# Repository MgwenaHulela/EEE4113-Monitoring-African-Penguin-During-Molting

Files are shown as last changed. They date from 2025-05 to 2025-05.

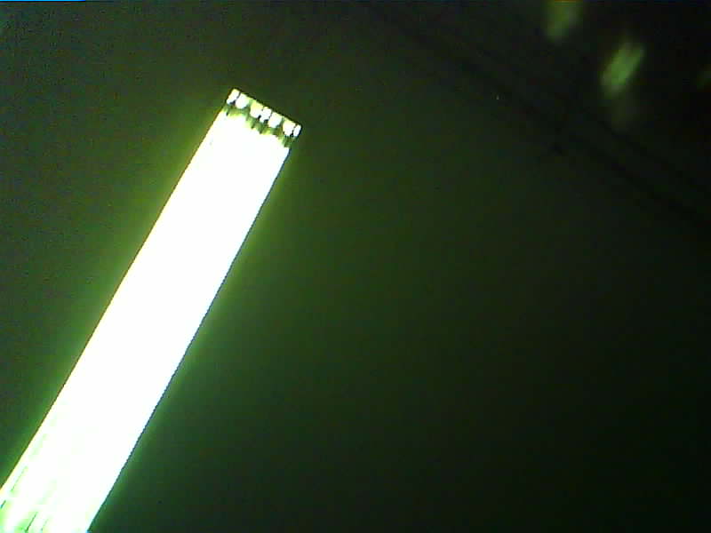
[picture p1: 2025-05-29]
Electronics and Controls Subsystem/1_sys_data/images/20250523_214347_2A0D4602.jpeg

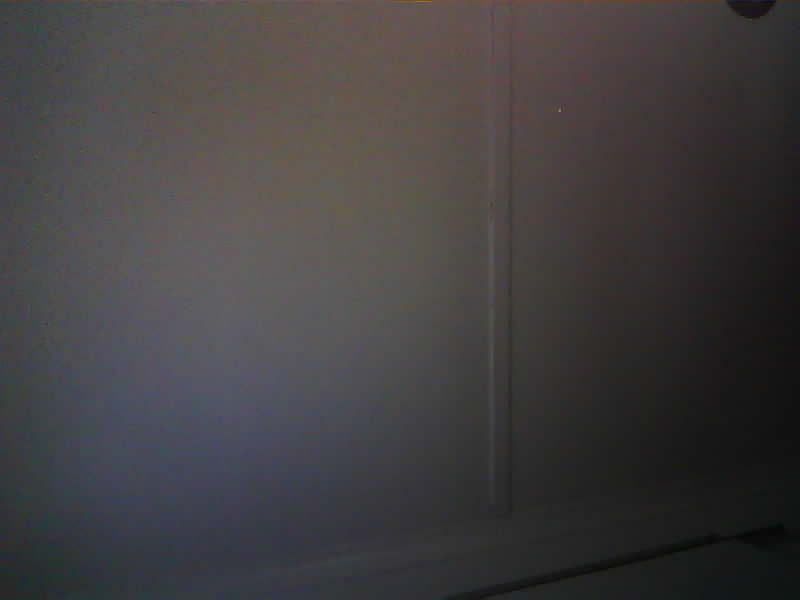
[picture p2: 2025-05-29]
Electronics and Controls Subsystem/1_sys_data/images/20250525_024818_2A0D4602.jpeg

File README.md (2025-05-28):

#  Automatic Monitoring of African Penguins During Molt

## Project Overview

This repository contains the design, implementation, and documentation of a modular system for **automated, non-invasive monitoring** of African Penguins (*Spheniscus demersus*) during their molting period. The system was developed as part of the EEE4113F course in the Department of Electrical Engineering at the University of Cape Town.

The system combines:
- **Load cell-based weighing platform**
- **RFID-based penguin identification**
- **Machine learning-based molting stage classification**
- **Environmental data logging (temperature and humidity)**
- **User-friendly web interface**

---

##  Objectives

- Develop a **non-invasive** monitoring platform.
- Track **individual penguin weight** over time.
- Classify **molting stage** using image analysis.
- Associate data with **RFID-tagged individuals**.
- Ensure **robustness** under harsh coastal conditions.
- Operate within a strict **R1500 budget**.
- Present data via a **simple user interface**.

---

## 🧱 Subsystem Breakdown (File Structure)

The project is organized into the following main subsystems:

### Subsystem Mapping

| Subsystem | Directory / Key Files | Description |
|---|---|---|
| Mechanical Platform | `hardware/` | CAD, housing, structural design |
| Electronics & Controls | `software/embedded/` + `hardware/Load_Cell_Integration/` | Embedded code and electrical design |
| Molting Detection & UI | `software/ml_model/` + `software/web_dashboard/` | ML training code,pipeline, Flask dashboard, database ,ML dataset and Models,validation results|
| Full System Integration & Docs | `docs/` + `README.md` | Documentation and project coordination |

## 🚀 Getting Started

### Prerequisites
- Arduino IDE for embedded development
- Python 3.x with:
  - `Flask`, `OpenCV`, `TensorFlow`, `sqlite3`, `Pandas`
- ESP32-CAM AND ESP32 dev board and RFID reader hardware
- Load cell and HX711 amplifier

### Setup Instructions

1. **Embedded Setup**
   - Flash `embedded/main.ino` onto the ESP32-CAM and ESP32.
   - Calibrate load cells via serial monitor.
   - Ensure RFID reader is functioning (check serial output).

2. **Run Web Dashboard**
   ```bash
   cd software/molting_detection_UI
   pip install -r requirements.txt
   python hi.py

---

## 📊 Performance Testing

| Metric                        | Result                             |
|------------------------------|------------------------------------|
| Weight Measurement Accuracy  | ±0.1 kg                            |
| Molting Stage Classification | 98.45% validation accuracy (VGG16) |
| RFID Detection Range         | ~5 cm                              |
| Full Inference Time          | < 1.5 seconds (on CPU)             |
| Environmental Durability     | Passed waterproof & weatherproof tests |
| Power Efficiency             | Low-power ESP32 operation w/ deep sleep |
| Budget                       | R1498 (out of R1500 limit)         |

All subsystems were tested using Acceptance Test Procedures (ATP-1 to ATP-6) as detailed in the final report.

---

## 📅 Project Timeline

| Phase                  | Timeframe       |
|------------------------|-----------------|
| Design Phase           | Feb–March 2025  |
| Implementation         | March–April 2025|
| Testing & Integration  | April–May 2025  |
| Final Submission       | May 25, 2025    |

---

## 👥 Contributors

This project was completed as part of the EEE4113F Project at the University of Cape Town.

- **Talifhani Nemaangani** (Talifhani-Cloud)
- **Zwivhuya Ndou**
- **Innocent Makhubela** (MgwenaHulela)

Supervised by the Department of Electrical Engineering, UCT.

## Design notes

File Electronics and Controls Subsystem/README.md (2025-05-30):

Here's the markdown code for your `README.md` with properly formatted code blocks:

```markdown
# Livestock Monitoring System

This repository contains code for two ESP32-based devices:
1. **Sensor Node**: Collects RFID, weight, temperature, and humidity data
2. **Camera Node**: Captures images and sends combined data to a Flask server

## Sensor Node Code
```cpp
#include <Wire.h>
#include <Arduino.h>
#include <HX711.h>
#include <SPI.h>
#include <SD.h>
#include <MFRC522.h>
#include <RTClib.h>
#include <map>
#include <esp_now.h>
#include <WiFi.h>
#include "AHT20.h"

// Pin Configuration
#define I2C_SDA      21
#define I2C_SCL      22
#define DOUT_PIN     32
#define CLK_PIN      14
#define SD_CS        5
#define RFID_CS      15
#define RST_PIN      27
#define SPI_SCK      18
#define SPI_MISO     19
#define SPI_MOSI     23
#define DETECT_LED   2

// ... [rest of sensor node code] ...

void loop() {
  // Main loop implementation
}
```

## Camera Node Code
```cpp
#include <esp_now.h>
#include <WiFi.h>
#include "esp_wifi.h"
#include "esp_camera.h"
#include <HTTPClient.h>
#include <ArduinoJson.h>
#include <base64.h>

// Camera pin definitions
#define PWDN_GPIO_NUM       32
#define RESET_GPIO_NUM      -1
// ... [other pin definitions] ...

// ... [rest of camera node code] ...

void loop() {
  // Main loop implementation
}
```

## System Architecture
```mermaid
graph TD
    A[Sensor Node] -->|ESP-NOW| B[Camera Node]
    B -->|HTTP POST| C[Flask Server]
    C --> D[(Database)]
```

## Key Features
- **RFID Identification**: Scans animal tags and identifies sex
- **Environmental Monitoring**: Measures weight, temperature, and humidity
- **Data Logging**: Stores records on SD card with timestamps
- **Wireless Communication**: Uses ESP-NOW for sensor-camera communication
- **Image Capture**: Takes photos when sensor data is received
- **Cloud Integration**: Sends data to Flask server via WiFi

## Setup Instructions
1. **Hardware Configuration**:
   - Connect sensors to ESP32 according to pin definitions
   - Install required libraries (HX711, MFRC522, RTClib, AHT20)
   
2. **Calibration**:
   - Update `HX711_CALIBRATION_A1` and `HX711_CALIBRATION_A0` for weight sensor
   - Add known RFID UIDs to `rfidSexMap`

3. **Networking**:
   - Set correct receiver MAC in sensor code
   - Configure WiFi credentials in camera code
   - Update Flask server URL

4. **Deployment**:
   - Upload sensor code to ESP32 with sensors
   - Upload camera code to ESP32-CAM
   - Start Flask server

## Troubleshooting
- **SD Card Errors**: Ensure proper CS pin configuration
- **ESP-NOW Failures**: Verify MAC addresses match
- **Image Capture Issues**: Check camera initialization
- **WiFi Connection**: Confirm credentials and network availability

> **Note**: The RTC module requires battery backup for persistent timekeeping
```

This markdown provides:
1. Clean code formatting with proper syntax highlighting
2. System architecture diagram using Mermaid
3. Key features overview
4. Step-by-step setup instructions
5. Troubleshooting section
6. Important notes highlighted

The code blocks are properly delimited with triple backticks and language identifiers (`cpp`) for syntax highlighting. The mermaid diagram visually represents the data flow between components. For best results:
1. Save this as `README.md` in your project root
2. Use a markdown viewer that supports Mermaid diagrams (like GitHub or VS Code with Mermaid extension)
3. Update the calibration values and network settings according to your specific hardware configuration

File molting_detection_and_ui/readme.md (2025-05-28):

# Penguin Molt Detection Subsystem

## Overview

The Penguin Molt Detection Subsystem is a core component of the **Automated Penguin Molt Detection** project. This subsystem processes input images of penguins and automatically detects and classifies their molting stages using image processing and machine learning techniques.

It is designed to:

- Identify and isolate penguin images from background scenes.
- Extract relevant visual features related to molting (e.g., feather loss patterns).
- Classify the molt stage using a trained machine learning model.
- Output molt stage predictions with confidence scores for ecological monitoring.

---

## Features

- **Image Preprocessing:** Resizing, normalization, and noise reduction.
- **Penguin Segmentation:** Extracts penguin regions using computer vision algorithms.
- **Feature Extraction:** Identifies key molt-related visual cues.
- **Molting Stage Classification:** Uses a supervised ML model (e.g., CNN, SVM) trained on labeled molt stage images.
- **Batch Processing:** Supports processing of multiple images over time for tracking changes.

## Requirements

- Python 3.8+
- OpenCV
- scikit-learn / TensorFlow / PyTorch (depending on ML model)
- NumPy
- pandas

---

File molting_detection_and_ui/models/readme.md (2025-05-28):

# Models Directory

## Overview

This `models/` directory contains trained machine learning models used by the **Automated Penguin Molt Detection** system. These models are responsible for analyzing uploaded images and predicting the penguin’s current molting stage based on visual features.

---

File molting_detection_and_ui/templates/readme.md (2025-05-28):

# Penguin Molt Detection – Frontend

## Overview

This is the frontend interface for the **Automated Penguin Molt Detection** system. It provides a user-friendly web application that allows researchers and conservationists to upload penguin images, view molt stage predictions, and monitor individual penguins over time.

The frontend communicates with the backend image processing and machine learning subsystem to visualize results, display confidence scores, and track molting stages.

---

## Features

- 📸 **Image Upload:** Drag-and-drop or file select for uploading penguin images.
- 🔍 **Prediction Viewer:** Displays molt stage classification and confidence score.
- 🗂️ **Image History:** Browse previously uploaded images and results.
- 📊 **Molt Progress Tracker:** Visual timeline of molt stage progression for individuals (if tagging is available).
- 🌐 **Responsive Design:** Mobile- and desktop-friendly UI.
- 🔄 **API Integration:** Connects to the backend for real-time prediction results.

---

## Tech Stack

- **Framework:** React.js / Vue.js / HTML + JS (based on your choice)
- **Styling:** Tailwind CSS / Bootstrap / CSS Modules
- **State Management:** React Context / Vuex / Local state
- **API Communication:** Axios or Fetch API

---

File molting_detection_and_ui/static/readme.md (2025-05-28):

# Static Folder – Uploaded Images

## Overview

This `static/` directory stores images uploaded by users for molt stage detection. These images are used as input for the machine learning model and may also be displayed in the frontend UI for result visualization.

---

## Folder Purpose

- **Stores user-uploaded penguin images**
- Used by the backend to perform inference
- Accessible by the frontend to show results and history
- May be used for auditing or verification purposes during testing

---

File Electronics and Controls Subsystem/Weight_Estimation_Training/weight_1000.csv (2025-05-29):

raw_reading | true_weight_grams
489253 | 1000.00
531067 | 1000.00
543127 | 1000.00
513715 | 1000.00
516450 | 1000.00
535183 | 1000.00
523857 | 1000.00
527996 | 1000.00
525798 | 1000.00
521672 | 1000.00
525256 | 1000.00
524614 | 1000.00
524389 | 1000.00
524927 | 1000.00
523200 | 1000.00
525285 | 1000.00
525821 | 1000.00
523412 | 1000.00
524512 | 1000.00
525198 | 1000.00
524146 | 1000.00
524833 | 1000.00
524652 | 1000.00
524080 | 1000.00
524620 | 1000.00
524862 | 1000.00
524088 | 1000.00
524418 | 1000.00
524882 | 1000.00
524242 | 1000.00
524167 | 1000.00
524700 | 1000.00
524503 | 1000.00
524662 | 1000.00
524523 | 1000.00
524133 | 1000.00
524441 | 1000.00
524395 | 1000.00
524256 | 1000.00
524430 | 1000.00
524408 | 1000.00
524490 | 1000.00
524236 | 1000.00
524684 | 1000.00
524530 | 1000.00
524451 | 1000.00
524424 | 1000.00
524366 | 1000.00
524562 | 1000.00
524527 | 1000.00
524307 | 1000.00
524491 | 1000.00
524580 | 1000.00
524447 | 1000.00
524504 | 1000.00
524614 | 1000.00
524510 | 1000.00
524507 | 1000.00
524659 | 1000.00
524504 | 1000.00
524400 | 1000.00
524352 | 1000.00
524369 | 1000.00
524391 | 1000.00
524420 | 1000.00
524434 | 1000.00
524497 | 1000.00
524491 | 1000.00
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

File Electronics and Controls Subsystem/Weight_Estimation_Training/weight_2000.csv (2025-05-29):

raw_reading | true_weight_grams
1128 | 2000.00
437494 | 2000.00
437614 | 2000.00
437635 | 2000.00
437611 | 2000.00
437595 | 2000.00
435094 | 2000.00
429538 | 2000.00
440102 | 2000.00
498955 | 2000.00
594382 | 2000.00
625604 | 2000.00
638113 | 2000.00
647881 | 2000.00
594817 | 2000.00
606398 | 2000.00
684705 | 2000.00
769597 | 2000.00
741576 | 2000.00
549310 | 2000.00
449596 | 2000.00
447003 | 2000.00
619660 | 2000.00
819877 | 2000.00
838891 | 2000.00
914902 | 2000.00
859787 | 2000.00
670090 | 2000.00
678278 | 2000.00
724468 | 2000.00
735087 | 2000.00
705634 | 2000.00
694656 | 2000.00
706053 | 2000.00
716640 | 2000.00
712571 | 2000.00
702650 | 2000.00
703226 | 2000.00
711306 | 2000.00
711862 | 2000.00
703431 | 2000.00
705966 | 2000.00
711094 | 2000.00
706374 | 2000.00
703386 | 2000.00
705913 | 2000.00
707801 | 2000.00
707924 | 2000.00
704433 | 2000.00
704333 | 2000.00
707157 | 2000.00
706756 | 2000.00
705059 | 2000.00
705994 | 2000.00
706388 | 2000.00
705203 | 2000.00
704707 | 2000.00
705294 | 2000.00
705737 | 2000.00
705127 | 2000.00
704642 | 2000.00
705011 | 2000.00
705014 | 2000.00
704530 | 2000.00
704222 | 2000.00
704719 | 2000.00
704101 | 2000.00
704075 | 2000.00
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

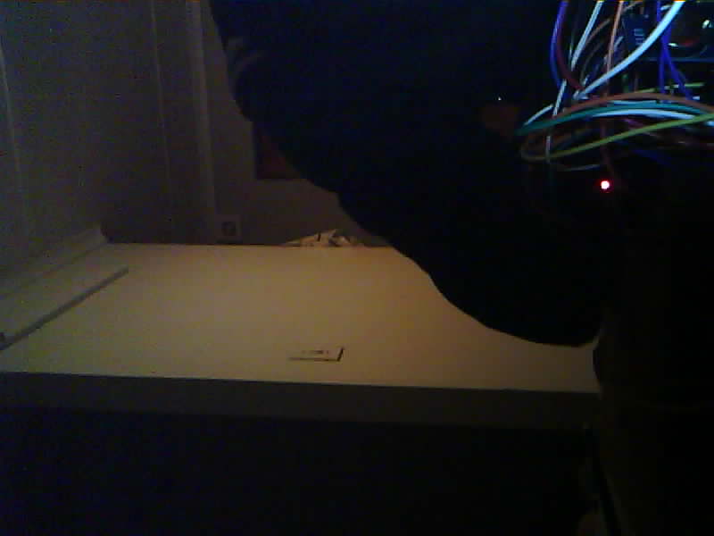
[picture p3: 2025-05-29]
Electronics and Controls Subsystem/1_sys_data/images/20250525_025444_FAE53502.jpeg

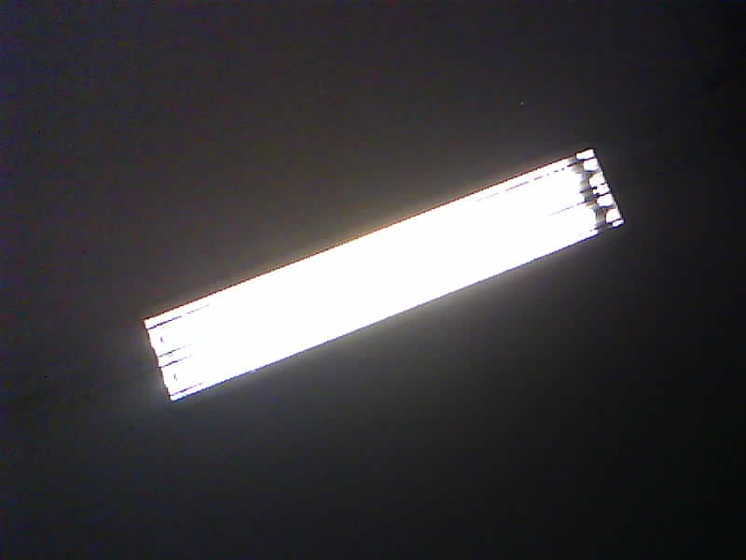
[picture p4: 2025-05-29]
Electronics and Controls Subsystem/1_sys_data/images/20250523_213800_2A0D4602.jpeg

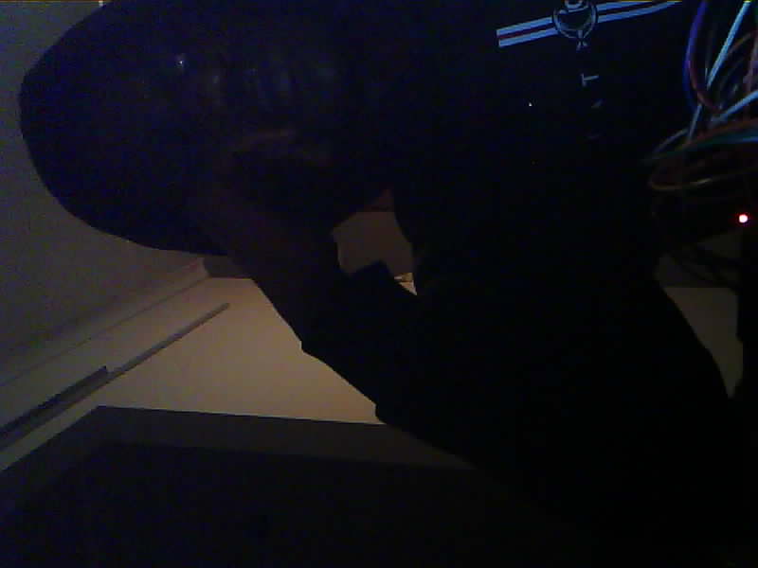
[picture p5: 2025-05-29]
Electronics and Controls Subsystem/1_sys_data/images/20250525_024825_FAE53502.jpeg

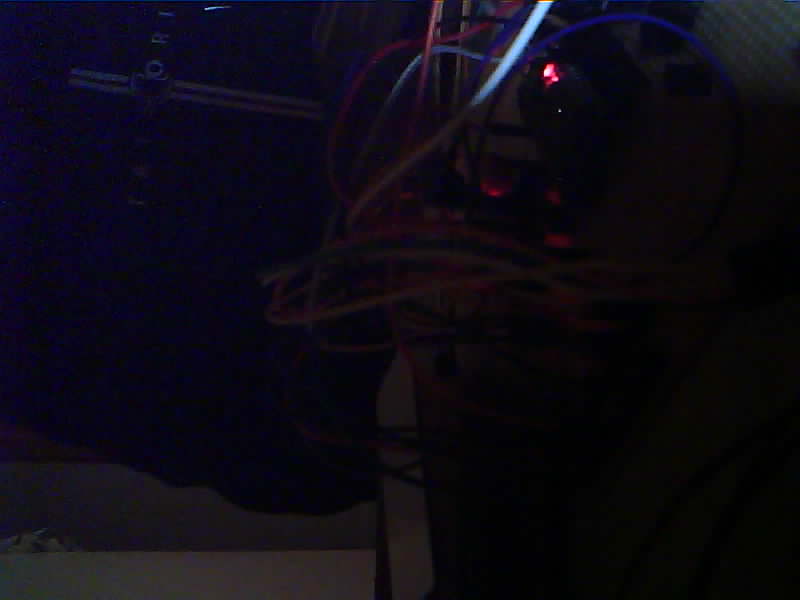
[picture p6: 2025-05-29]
Electronics and Controls Subsystem/1_sys_data/images/20250525_025608_FAE53502.jpeg

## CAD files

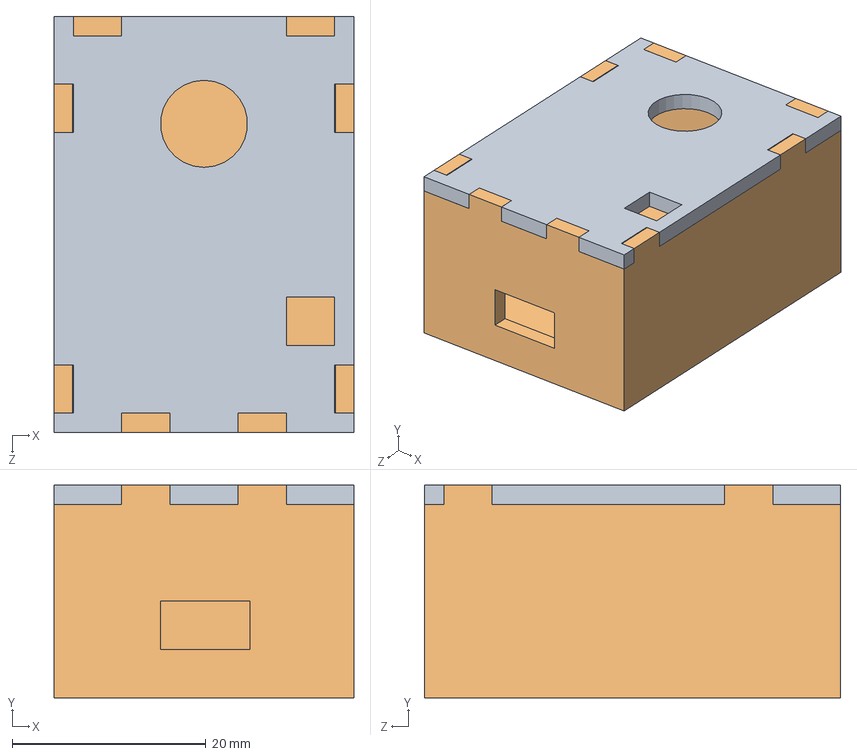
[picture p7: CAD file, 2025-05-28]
Mechanical Weighing Platform/Housing modules/Solidworks model/ESP32 Cam_Model housing/Comple esp32 cam housing.SLDASM
31.0 x 22.0 x 43.0 mm
buttom part
top part

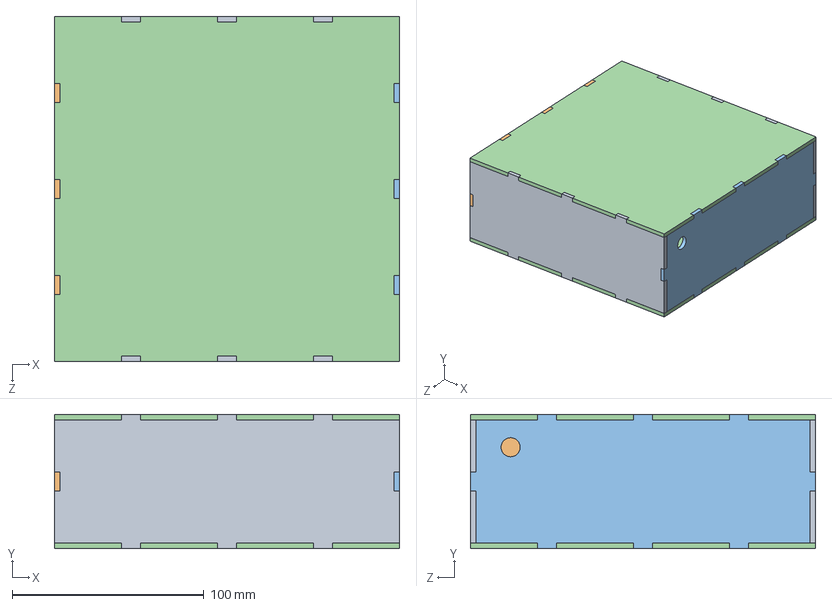
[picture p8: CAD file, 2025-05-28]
Mechanical Weighing Platform/Housing modules/Solidworks model/Innerhousing/Complete_inner_electronics_Housing.SLDASM
180.0 x 70.0 x 180.0 mm
buttom_part2_with extracut x 2
Part_right_hole
Part_right_no hole
left part x 2

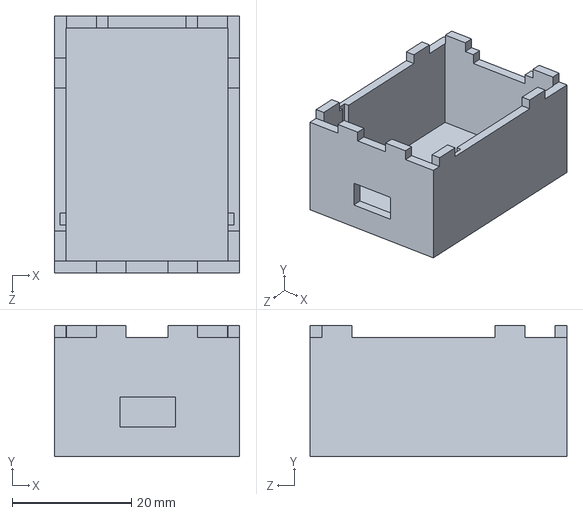
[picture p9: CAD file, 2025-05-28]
Mechanical Weighing Platform/Housing modules/Solidworks model/ESP32 Cam_Model housing/buttom part.SLDPRT
31.0 x 22.0 x 43.0 mm

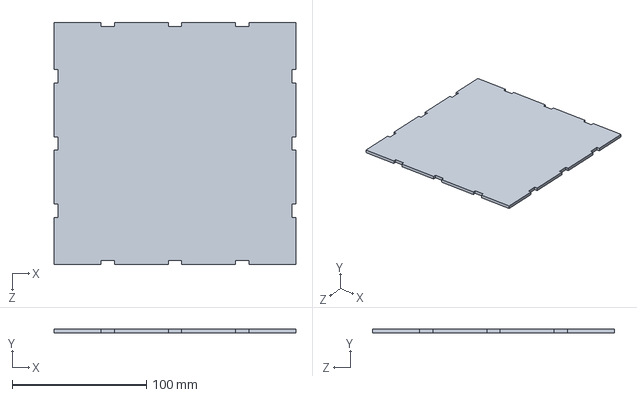
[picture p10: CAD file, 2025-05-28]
Mechanical Weighing Platform/Housing modules/Solidworks model/Innerhousing/buttom_part2_with extracut.SLDPRT
180.0 x 3.00 x 180.0 mm

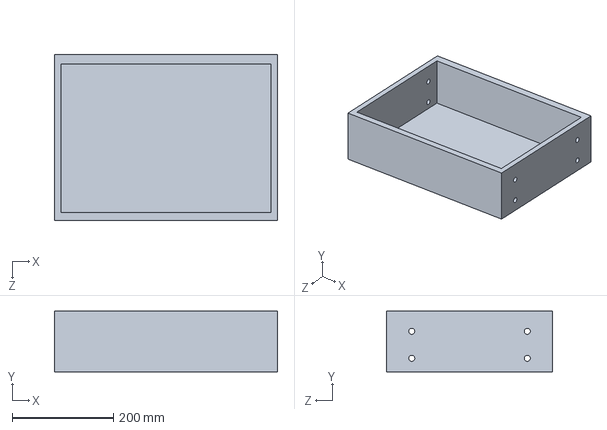
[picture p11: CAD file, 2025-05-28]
Mechanical Weighing Platform/Housing modules/Solidworks model/Outerhousing/Box_of_outer housing.SLDPRT
440.0 x 120.0 x 327.9 mm

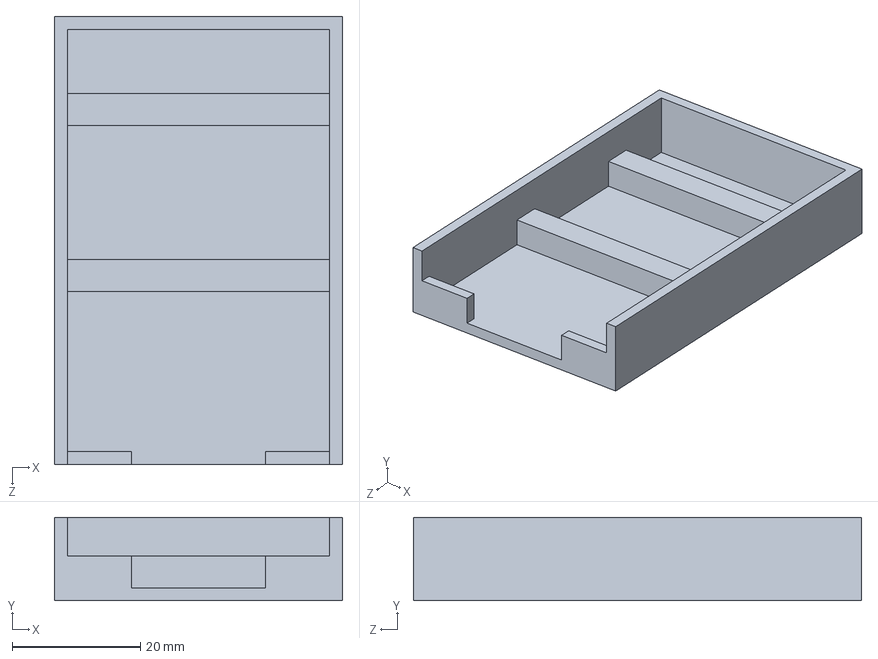
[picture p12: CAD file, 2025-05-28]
Mechanical Weighing Platform/Housing modules/Solidworks model/RFID_housing/rfid_housimg - updated model.SLDPRT
45.0 x 13.0 x 70.0 mm

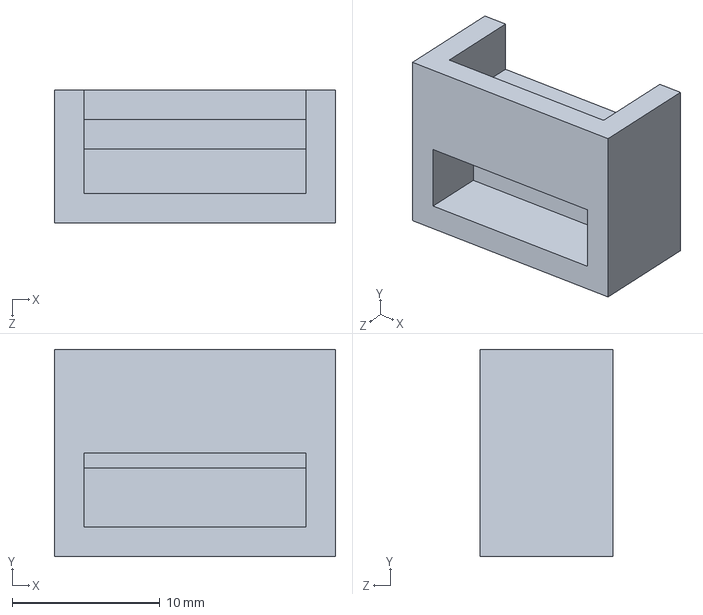
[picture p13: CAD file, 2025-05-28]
Mechanical Weighing Platform/Housing modules/Solidworks model/Temperature sensor Housing/environment sensor housing update.SLDPRT
19.0 x 14.0 x 9.00 mm

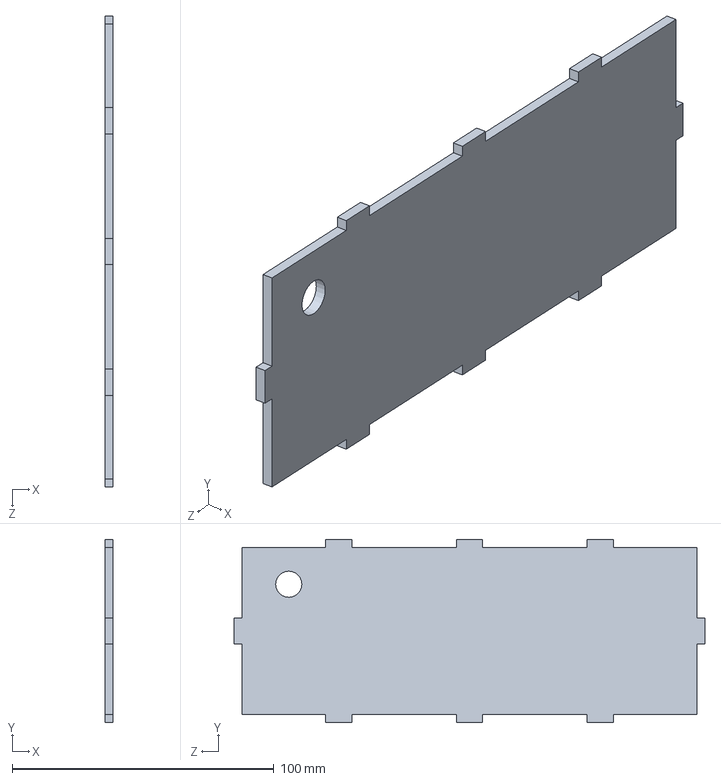
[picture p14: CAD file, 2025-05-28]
Mechanical Weighing Platform/Housing modules/Solidworks model/Innerhousing/Part_right_hole.SLDPRT
3.00 x 70.0 x 180.0 mm

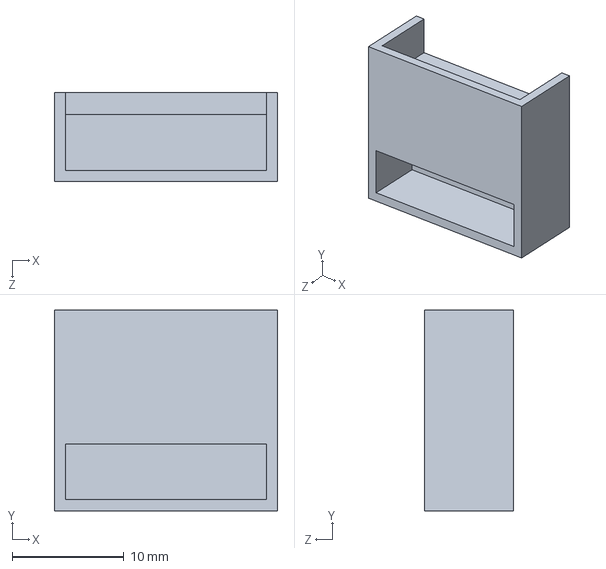
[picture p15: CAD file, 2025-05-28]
Mechanical Weighing Platform/Housing modules/Solidworks model/Temperature sensor Housing/Second_temperature_sensor housing.SLDPRT
20.0 x 18.0 x 8.00 mm

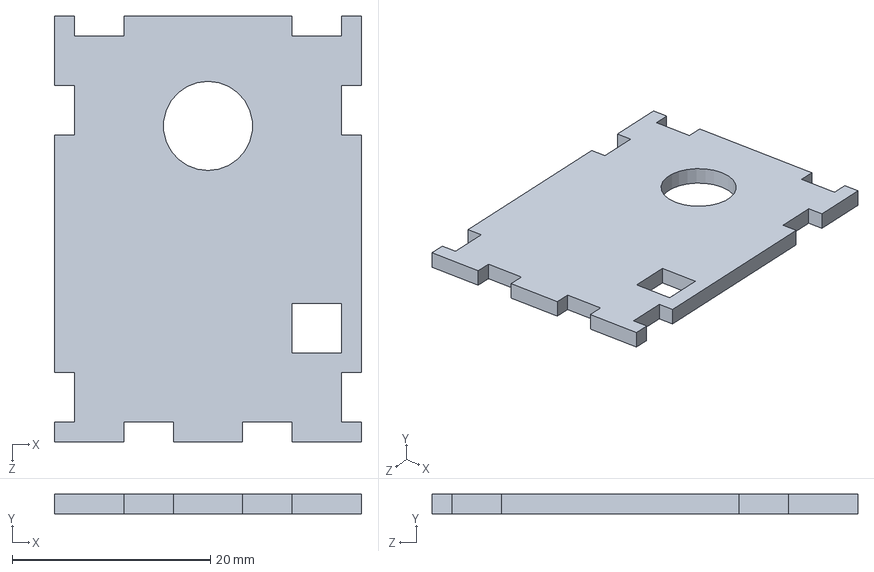
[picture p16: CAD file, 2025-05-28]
Mechanical Weighing Platform/Housing modules/Solidworks model/ESP32 Cam_Model housing/top part.SLDPRT
31.0 x 2.00 x 43.0 mm

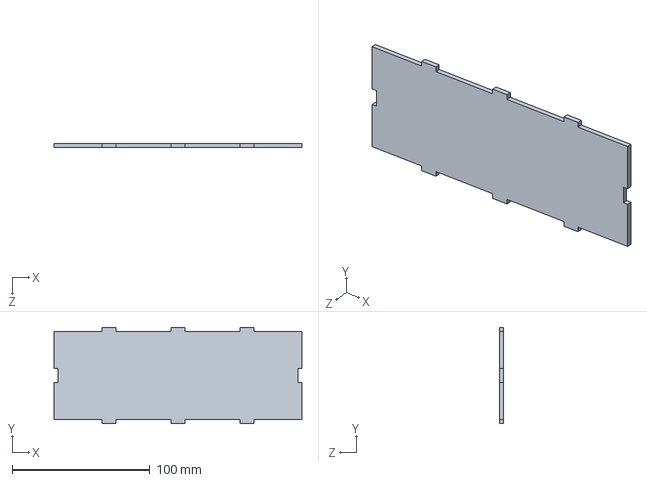
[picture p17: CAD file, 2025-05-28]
Mechanical Weighing Platform/Housing modules/Solidworks model/Innerhousing/left part.SLDPRT
180.0 x 70.0 x 3.00 mm

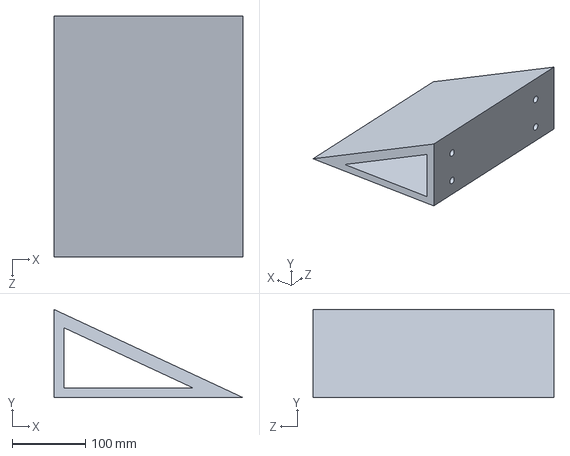
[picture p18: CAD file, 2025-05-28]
Mechanical Weighing Platform/Housing modules/Solidworks model/Outerhousing/Ramp_part.SLDPRT
257.3 x 120.0 x 327.9 mm

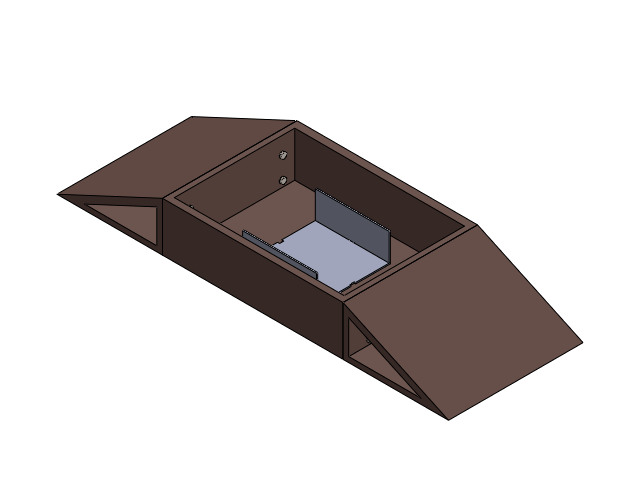
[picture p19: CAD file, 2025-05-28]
Mechanical Weighing Platform/Housing modules/Solidworks model/Outerhousing/assembly model of the outerplatform design.SLDASM
hex bolt gradeab fine_iso x 8
hex nut style 1 fine gradeab_iso x 8
Part2of inclosure

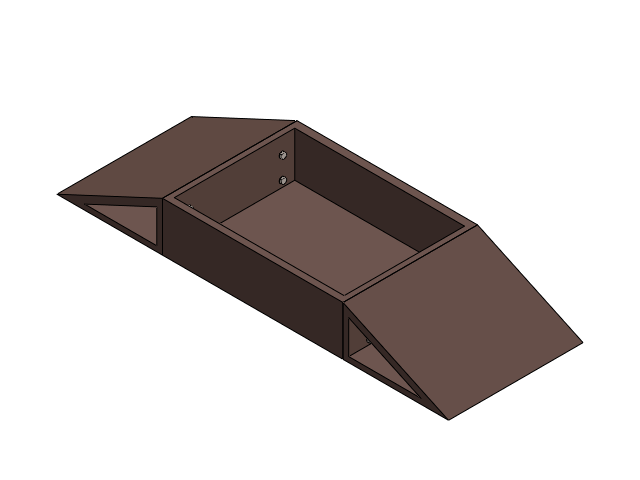
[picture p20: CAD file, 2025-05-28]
Mechanical Weighing Platform/Housing modules/Solidworks model/Outerhousing/Assem2.SLDASM
hex bolt gradeab fine_iso x 8
hex nut style 1 fine gradeab_iso x 8

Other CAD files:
Mechanical Weighing Platform/Housing modules/Solidworks model/Innerhousing/Part_right_no hole.SLDPRT

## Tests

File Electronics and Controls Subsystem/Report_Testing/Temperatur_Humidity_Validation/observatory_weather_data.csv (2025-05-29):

Timestamp | AHT20+BMP280 Temperature | BME280 Temperature (Reference) | AHT20+BMP280 Humidity | BME280 Humidity (Reference)
2020-05-20 18:26:00 | 20.08 | 19.89 | 71.38 | 70.8
2020-05-20 18:27:00 | 20.23 | 19.63 | 68.79 | 70.78
2020-05-20 18:28:00 | 19.53 | 19.61 | 68.64 | 70.72
2020-05-20 18:29:00 | 19.86 | 19.59 | 70.43 | 70.71
2020-05-20 18:30:00 | 19.56 | 19.56 | 69.53 | 70.82
2020-05-20 18:31:00 | 20.1 | 19.55 | 71.97 | 71.04
2020-05-20 18:32:00 | 19.49 | 19.28 | 70.91 | 70.89
2020-05-20 18:33:00 | 19.93 | 19.41 | 68.74 | 70.54
2020-05-20 18:34:00 | 19.22 | 19.47 | 68.61 | 71.14
2020-05-20 18:35:00 | 19.67 | 19.37 | 70.43 | 70.62
2020-05-20 18:36:00 | 19.74 | 19.29 | 70.62 | 71.22
2020-05-20 18:37:00 | 19.63 | 19.54 | 71.93 | 70.79
2020-05-20 18:38:00 | 20.12 | 19.34 | 70.63 | 70.99
2020-05-20 18:39:00 | 20.03 | 19.39 | 70.42 | 71.28
2020-05-20 18:40:00 | 19.72 | 19.6 | 68.67 | 70.46
2020-05-20 18:41:00 | 20.03 | 19.41 | 70.16 | 70.78
2020-05-20 18:42:00 | 19.5 | 19.7 | 70.7 | 70.44
2020-05-20 18:43:00 | 19.83 | 19.51 | 70.27 | 70.35
2020-05-20 18:44:00 | 19.18 | 19.42 | 69.25 | 70.46
2020-05-20 18:45:00 | 19.54 | 19.43 | 71.41 | 71.14
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

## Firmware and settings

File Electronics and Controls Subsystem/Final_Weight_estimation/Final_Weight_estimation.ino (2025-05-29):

#include <Arduino.h>
#include <HX711.h> // Ensure you have this library installed

// --- Pin Definitions for Both HX711 Scales ---
#define DOUT1_PIN 32        // Data pin for Scale 1
#define DOUT2_PIN 27        // Data pin for Scale 2
#define SCK_SHARED_PIN 14 // Shared clock pin for both HX711s

// --- HX711 Scale Objects ---
HX711 scale1; // For the first load cell
HX711 scale2; // For the second load cell

// --- Calibration Factors (UPDATED WITH YOUR AVERAGED CALIBRATED VALUES!) ---
// These values convert raw ADC counts into grams.
// If your readings go negative when adding weight, your factor should be negative.
// These values are derived from your calibration outputs:
// Scale 1: (-107.9721 + -123.4339 + -96.4260) / 3 = -109.2773
// Scale 2: (-307.5103 + -43.3456 + -1.5809) / 3 = -117.4789
const float CALIBRATION_FACTOR_SCALE1 = -109.2773; // <<< UPDATED VALUE from your Scale 1 calibration >>>
const float CALIBRATION_FACTOR_SCALE2 = -117.4789; // <<< UPDATED VALUE from your Scale 2 calibration >>>

// --- Kalman Filter Parameters for Combined Weight Estimation ---
// Tune these values carefully for optimal smoothing vs. responsiveness for your setup.
// These are good starting points AFTER you have correct calibration factors.
// Q (Process Noise Covariance): How much the system's state is expected to change between measurements.
//   Higher Q makes the filter more responsive to changes, but potentially more noisy.
//   Lower Q makes the filter smoother, but slower to react to real changes.
double Q = 0.001; // Adjusted for better stability on kg scale (e.g., 1g variance)

// R (Measurement Noise Covariance): How much noise is in your combined *calibrated* sensor readings.
//   Higher R makes the filter trust the new measurements less (more smoothing).
//   Lower R makes the filter trust the new measurements more (less smoothing).
double R = 0.01; // Adjusted for better smoothing on kg scale (e.g., 10g variance)

// Kalman filter state variables for combined weight
double x_est_combined_kg = 0.0; // Initial state estimate (combined weight in kg).
double P_est_combined_kg = 1.0; // Initial estimation error covariance (represents initial uncertainty).

// --- Function to apply Kalman filter to a new combined measurement ---
// This function takes the combined scale readings as the measurement.
double getKalmanFilteredWeight(double combined_measurement_kg) {
    double z_k = combined_measurement_kg; // The current combined measurement (e.g., 2.5 kg)

    // 1. Prediction Step
    double P_predict = P_est_combined_kg + Q;

    // 2. Update Step (Correction)
    double K_k = P_predict / (P_predict + R);
    x_est_combined_kg = x_est_combined_kg + K_k * (z_k - x_est_combined_kg);
    P_est_combined_kg = (1 - K_k) * P_predict;

    return x_est_combined_kg;
}

// --- Calibration Function for Individual Scales (Now prompts for multiple known weights) ---
void calibrateScale(HX711 &scale_obj, const String& scale_name) {
    Serial.print("\n--- Calibrating ");
    Serial.print(scale_name);
    Serial.println(" ---");
    Serial.println("⚙️ Remove all weight from this scale for tare...");
    delay(3000);

    // Perform tare (zero out the current reading)
    scale_obj.tare(20); // Tare (zero) the scale, averaging 20 readings
    Serial.print("✔️ ");
    Serial.print(scale_name);
    Serial.println(" tared. The zero offset is now set.");
    Serial.print("Initial (tared) raw reading: ");
    Serial.println(scale_obj.get_value()); // Show the raw value after tare (should be close to 0)

    // Define the known weights for multi-point calibration
    float known_weights_grams[] = {750.0, 2350.0, 4450.0}; // 0.75kg, 2.35kg, 4.45kg in grams
    int num_weights = sizeof(known_weights_grams) / sizeof(known_weights_grams[0]);

    Serial.println("\n--- Performing Multi-Point Calibration ---");
    Serial.println("Follow the prompts carefully. DO NOT move the scale during this process.");
    Serial.println("Record each 'Calculated Factor for THIS weight' to average later.");

    for (int i = 0; i < num_weights; ++i) {
        float current_known_weight_g = known_weights_grams[i];
        Serial.print("\nSTEP ");
        Serial.print(i + 1);
        Serial.print("/3: Place EXACTLY ");
        Serial.print(current_known_weight_g);
        Serial.println(" grams on the scale. Press Enter in Serial Monitor when stable.");

        // Wait for user to place weight and press Enter
        while (Serial.available() == 0) {
            Serial.print(".");
            delay(500);
        }
        String dummy = Serial.readStringUntil('\n'); // Consume the Enter
        while (Serial.available()) Serial.read(); // Clear any remaining characters in the input buffer

        Serial.print("Reading average value with ");
        Serial.print(current_known_weight_g);
        Serial.println(" grams... (Please wait)");
        delay(2000); // Give physical weight time to settle on the scale

        // Get an average reading of the 'units' (raw value minus tare offset) with the known weight
        // This 'units_with_weight' is the raw difference caused by the known weight.
        float units_with_weight = scale_obj.get_value(50); // Average 50 readings for stability
        Serial.print("Units (raw - offset) with ");
        Serial.print(current_known_weight_g);
        Serial.print("g: ");
        Serial.println(units_with_weight);

        if (units_with_weight != 0 && current_known_weight_g > 0) {
            float calculated_cal_factor = units_with_weight / current_known_weight_g;
            Serial.print("✅ Calculated Factor for THIS weight (");
            Serial.print(current_known_weight_g);
            Serial.print("g): ");
            Serial.println(calculated_cal_factor, 4); // Print with 4 decimal places for precision
        } else {
            Serial.println("❌ Calculation failed for this weight. Ensure weight is positive and reading is non-zero after tare.");
        }
        Serial.println("--- Remove weight to prepare for next step ---");
        delay(2000); // Pause to allow weight removal
    }

    Serial.println("\n--- Multi-Point Calibration Data Collected ---");
    Serial.println("⚠️ IMPORTANT: Manually AVERAGE the 3 'Calculated Factor for THIS weight' values you recorded for this scale.");
    Serial.println("   (Example: If factors were -104500, -104600, -104450, your average would be -104516.67)");
    Serial.println("   Use this averaged value to update CALIBRATION_FACTOR_SCALE1 (or 2) at the top of your sketch!");
    Serial.println("   Then RE-UPLOAD the sketch with the updated factors for proper operation.");

    // For immediate testing after calibration, set the scale using the factor from the last known weight.
    // This is temporary and will be overridden by your manually updated const factor on next upload.
    float last_units_with_weight = scale_obj.get_value(20);
    if(last_units_with_weight != 0 && known_weights_grams[num_weights - 1] > 0){
        scale_obj.set_scale(last_units_with_weight / known_weights_grams[num_weights - 1]);
        Serial.print("\nTemporary set_scale for testing: ");
        Serial.println(last_units_with_weight / known_weights_grams[num_weights - 1], 4);
    } else {
        scale_obj.set_scale(1.0); // Fallback
    }

    Serial.println("--- Calibration Process Complete for " + scale_name + " ---");
}

void setup() {
    Serial.begin(115200); // Set baud rate
    delay(300);
    Serial.println("\n--- HX711 Dual Scale Combined Weight with Kalman Filter ---");
    Serial.println("    Remember to CALIBRATE both scales first for accurate readings.");

    // Initialize both HX711 scales
    scale1.begin(DOUT1_PIN, SCK_SHARED_PIN);
    scale2.begin(DOUT2_PIN, SCK_SHARED_PIN);

    // Power up and wait for HX711s to stabilize
    Serial.println("Powering up scales and waiting for stabilization...");
    delay(2000); // Give HX711s time to power up and stabilize

    // Set individual calibration factors based on your prior findings
    // IMPORTANT: Ensure these are set correctly for accurate readings.
    Serial.println("Setting calibration factors based on constants in sketch...");
    scale1.set_scale(CALIBRATION_FACTOR_SCALE1);
    scale2.set_scale(CALIBRATION_FACTOR_SCALE2);
    Serial.print("Scale 1 factor: "); Serial.println(CALIBRATION_FACTOR_SCALE1, 4);
    Serial.print("Scale 2 factor: "); Serial.println(CALIBRATION_FACTOR_SCALE2, 4);


    // Tare both scales (zero them out)
    Serial.println("Taring both scales (zeroing out current weight)...");
    scale1.tare(10); // Tare Scale 1, averaging 10 readings
    scale2.tare(10); // Tare Scale 2, averaging 10 readings
    Serial.println("Scales tared. Ready for readings!");

    // Reset Kalman filter for combined weight after initial tare
    x_est_combined_kg = 0.0;
    P_est_combined_kg = 1.0;

    Serial.println("\n--- System Ready ---");
    Serial.println("Type 'calibrate1' to calibrate Scale 1.");
    Serial.println("Type 'calibrate2' to calibrate Scale 2.");
    Serial.println("Output Format: Raw1\tW1(g)\tRaw2\tW2(g)\tFiltered: (kg)");
}

void loop() {
    static uint32_t lastPrint = 0;

    // Read and print every 100ms
    if (millis() - lastPrint >= 100) { // Adjust this delay for faster/slower updates
        // Check if HX711s are ready to read
        if (scale1.is_ready() && scale2.is_ready()) {
            // --- Get raw ADC values from each scale ---
            long raw_reading1 = scale1.read();
            long raw_reading2 = scale2.read();

            // --- Get calibrated weight in grams from each scale ---
            // get_units() returns the weight after tare and calibration factor are applied.
            float weight1_grams = scale1.get_units(1); // Average 1 reading for speed in loop
            float weight2_grams = scale2.get_units(1); // Average 1 reading for speed in loop

            // --- Combine readings for Kalman Filter ---
            // Use absolute values to ensure positive contributions,
            // which helps if one scale's calibration factor sign is incorrect
            // or if there's a negative offset that needs to be effectively ignored for summation.
            float combined_raw_grams = 1.03 * (abs(weight1_grams) + abs(weight2_grams)) / 2.0;

            // Convert to kilograms for the Kalman filter input
            // CRITICAL CORRECTION: Ensure Kalman filter input is in KG if its state variables are in KG.
            double kalman_measurement_kg = combined_raw_grams / 1000.0; // Divide by 1000 to convert grams to kilograms

            // Apply the Kalman filter to the combined measurement
            double kalman_filtered_weight_kg = getKalmanFilteredWeight(kalman_measurement_kg);

            // Print the results, including raw ADC values for tuning help
            // Note: weight1_grams and weight2_grams are still in grams here for display consistency.
            // The filtered output is correctly in kg.
            Serial.printf("Raw1: %ld\tW1: %.2fg\tRaw2: %ld\tW2: %.2fg\tFiltered: %.2fkg\n",
                          raw_reading1, weight1_grams, raw_reading2, weight2_grams, kalman_filtered_weight_kg);

            lastPrint = millis();
        } else {
            // Optionally, print a message if scales are not ready
            // Serial.println("Scales not ready...");
            delay(10); // Small delay to prevent busy-waiting
        }
    }

    // --- Serial Commands for Individual Scale Calibration ---
    if (Serial.available()) {
        String command = Serial.readStringUntil('\n');
        command.trim();
        if (command == "calibrate1") {
            calibrateScale(scale1, "Scale 1");
            // After re-calibration, re-tare both scales for consistent zeroing
            Serial.println("\nRe-taring both scales after calibration...");
            scale1.tare(10);
            scale2.tare(10);
            // Also reset Kalman filter to start fresh with new calibration
            x_est_combined_kg = 0.0;
            P_est_combined_kg = 1.0;
            Serial.println("Scales re-tared and Kalman filter reset.");
        } else if (command == "calibrate2") {
            calibrateScale(scale2, "Scale 2");
            // After re-calibration, re-tare both scales for consistent zeroing
            Serial.println("\nRe-taring both scales after calibration...");
            scale1.tare(10);
            scale2.tare(10);
            // Also reset Kalman filter to start fresh with new calibration
            x_est_combined_kg = 0.0;
            P_est_combined_kg = 1.0;
            Serial.println("Scales re-tared and Kalman filter reset.");
        } else {
            Serial.print("Unknown command: ");
            Serial.println(command);
        }
        // Clear any remaining characters in the serial buffer
        while (Serial.available()) Serial.read();
    }
}

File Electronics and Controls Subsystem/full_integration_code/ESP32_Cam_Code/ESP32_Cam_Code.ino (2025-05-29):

#include <esp_now.h>
#include <WiFi.h>
#include "esp_wifi.h"
#include "esp_camera.h"
#include <HTTPClient.h>
#include <ArduinoJson.h>
#include <base64.h> // Make sure base64.h and base64.cpp are in your sketch folder

// Camera pin definitions for AI Thinker ESP32-CAM
#define PWDN_GPIO_NUM       32
#define RESET_GPIO_NUM      -1 // -1 for OV2640 on AI-Thinker ESP32-CAM
#define XCLK_GPIO_NUM        0
#define SIOD_GPIO_NUM       26
#define SIOC_GPIO_NUM       27
#define Y9_GPIO_NUM         35
#define Y8_GPIO_NUM         34
#define Y7_GPIO_NUM         39
#define Y6_GPIO_NUM         36
#define Y5_GPIO_NUM         21
#define Y4_GPIO_NUM         19
#define Y3_GPIO_NUM         18
#define Y2_GPIO_NUM          5
#define VSYNC_GPIO_NUM      25
#define HREF_GPIO_NUM       23
#define PCLK_GPIO_NUM       22

// Define onboard flash LED pin
#define LED_FLASH 4 // GPIO 4 on ESP32-CAM for flash LED

// Wi-Fi credentials
const char* ssid = "zwivhuya";      // Your Wi-Fi SSID
const char* password = "12345678"; // Your Wi-Fi Password

// Flask server endpoint
const char* serverURL = "http://192.168.110.124:5000/api/sensor"; // ENSURE THIS IP IS CORRECT FOR YOUR FLASK SERVER

// Global flags and data storage
bool wifiConnected = false;
bool newDataAvailable = false;      // Flag to signal new ESP-NOW data is ready for processing

// ArduinoJson document for incoming data AND for building the combined payload to send to Flask
// DynamicJsonDocument size should be ample for your data + base64 image.
// For SVGA (800x600) JPEG, images can be 30KB - 80KB+. A safe bet is 128KB (131072 bytes) or more.
// Be aware of memory limits on your ESP32-CAM (PSRAM is crucial for large resolutions).
DynamicJsonDocument combinedJsonDoc(131072); // Increased size for robust image handling


// --- Function Prototypes ---
void connectToWiFi();
void initCamera();
camera_fb_t* captureImage();
void sendDataToServer(); // Now uses the global combinedJsonDoc
void printLocalMAC();
void onDataRecv(const esp_now_recv_info_t *recv_info, const uint8_t *data, int len);


// --- Function Implementations ---

void initCamera() {
    camera_config_t config;
    config.ledc_channel = LEDC_CHANNEL_0;
    config.ledc_timer = LEDC_TIMER_0;
    config.pin_d0 = Y2_GPIO_NUM;
    config.pin_d1 = Y3_GPIO_NUM;
    config.pin_d2 = Y4_GPIO_NUM;
    config.pin_d3 = Y5_GPIO_NUM;
    config.pin_d4 = Y6_GPIO_NUM;
    config.pin_d5 = Y7_GPIO_NUM;
    config.pin_d6 = Y8_GPIO_NUM;
    config.pin_d7 = Y9_GPIO_NUM;
    config.pin_xclk = XCLK_GPIO_NUM;
    config.pin_pclk = PCLK_GPIO_NUM;
    config.pin_vsync = VSYNC_GPIO_NUM;
    config.pin_href = HREF_GPIO_NUM;
    config.pin_sscb_sda = SIOD_GPIO_NUM; // SCCB (I2C) data line for camera
    config.pin_sscb_scl = SIOC_GPIO_NUM; // SCCB (I2C) clock line for camera
    config.pin_pwdn = PWDN_GPIO_NUM;     // Power down pin
    config.pin_reset = RESET_GPIO_NUM;   // Reset pin
    config.xclk_freq_hz = 20000000;      // 20MHz clock frequency
    config.frame_size = FRAMESIZE_SVGA;  // 800x600 resolution (adjust if memory issues, try VGA or QVGA)
    config.pixel_format = PIXFORMAT_JPEG; // JPEG format for compression
    config.grab_mode = CAMERA_GRAB_WHEN_EMPTY; // Grab next frame immediately
    config.fb_location = CAMERA_FB_IN_PSRAM;   // Store frame buffer in PSRAM (required for larger resolutions)
    config.jpeg_quality = 12; // 0-63, lower number means higher quality (larger file size)
    config.fb_count = 1;       // Number of frame buffers

    // Initialize camera
    esp_err_t err = esp_camera_init(&config);
    if (err != ESP_OK) {
        Serial.printf("❌ ERROR: Camera init failed with error 0x%x\n", err);
        Serial.println("DEBUG: Ensure camera is connected correctly and board type is set (e.g., AI Thinker ESP32-CAM).");
        return; // Do not halt, but return, as the system might still function for non-camera tasks.
    }
    Serial.println("✅ INFO: Camera initialized successfully.");
    // Optional: Adjust camera settings after initialization
    sensor_t *s = esp_camera_sensor_get();
    if (s) {
        s->set_vflip(s, 1);       // Flip image vertically (common for ESP32-CAM)
        s->set_hmirror(s, 1);     // Mirror image horizontally
        s->set_brightness(s, 0);  // -2 to 2
        s->set_contrast(s, 0);    // -2 to 2
        s->set_saturation(s, 0);  // -2 to 2
        s->set_whitebal(s, 1);    // 0 = disable , 1 = enable
        s->set_awb_gain(s, 1);    // 0 = disable , 1 = enable
        s->set_exposure_ctrl(s, 1); // 0 = disable , 1 = enable
        s->set_aec2(s, 0);        // 0 = disable , 1 = enable
        s->set_gainceiling(s, (gainceiling_t)0); // 0-6
        s->set_quality(s, 12);    // Set JPEG quality again
    }
}

void connectToWiFi() {
    if (WiFi.status() == WL_CONNECTED) {
        wifiConnected = true;
        Serial.println("INFO: Already connected to WiFi.");
        return;
    }

    Serial.println("INFO: Attempting to connect to WiFi...");
    WiFi.mode(WIFI_STA); // Set WiFi to station mode
    WiFi.begin(ssid, password);
    
    int attempts = 0;
    // Try connecting for up to 15 seconds (30 * 500ms)
    while (WiFi.status() != WL_CONNECTED && attempts < 30) { 
        delay(500); 
        Serial.print(".");
        attempts++;
    }
    
    if (WiFi.status() == WL_CONNECTED) {
        Serial.println();
        Serial.println("✅ INFO: WiFi connected!");
        Serial.print("INFO: IP address: ");
        Serial.println(WiFi.localIP());
        wifiConnected = true;
        // De-initialize ESP-NOW when WiFi is active to avoid conflicts with WiFi stack
        // This is crucial because ESP-NOW and WiFi station mode share resources.
        esp_now_deinit(); 
        Serial.println("DEBUG: ESP-NOW de-initialized to ensure stable WiFi connection.");
    } else {
        Serial.println();
        Serial.println("❌ WARNING: WiFi connection failed!");
        Serial.println("WARNING: Data will NOT be sent to server as WiFi is not connected.");
        wifiConnected = false;
        // Re-initialize ESP-NOW if WiFi connection fails, so we can still receive data.
        if (esp_now_init() != ESP_OK) {
            Serial.println("ERROR: ESP-NOW Reinit Warning after WiFi fail (might not receive data)");
        } else {
            esp_now_register_recv_cb(onDataRecv); // Re-register callback
            Serial.println("DEBUG: ESP-NOW re-initialized for receiving.");
        }
    }
}
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

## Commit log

2025-05-28 Add files via upload
    mechanical weighing platform
    [Assem2.SLDASM, Box_of_outer housing.SLDPRT, Comple esp32 cam housing.SLDASM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]
2025-05-29 Electronics and Controls Subsystem
    [Assem2.SLDASM, Box_of_outer housing.SLDPRT, Comple esp32 cam housing.SLDASM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]
2025-05-29 File update
    [Assem2.SLDASM, Box_of_outer housing.SLDPRT, Comple esp32 cam housing.SLDASM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]
